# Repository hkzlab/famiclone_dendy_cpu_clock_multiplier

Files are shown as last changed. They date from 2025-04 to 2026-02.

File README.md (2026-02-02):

# Famiclone Dendy CPU clock multiplier

## DISCLAIMER

Any use of this project is **under your own responsibility**.
You will be responsible of checking the correct construction and functionality of your board.
By using this project You will agree that I cannot be held responsible if it will destroy any of your devices, damage your computer, burn down your house or whatever.

### Sponsorship

PCBWay_logo

This project is sponsored by [PCBWay](https://pcbway.com)!

PCBWay specializes in manufacturing high-quality PCBs and makes them affordable to hobbyist and professionals alike.

The range of services they offer include PCB prototyping, assembly, instant quotes for your order, a verification process by a team
of experts and an easy to use, hassle-free order process.

I am extremely grateful to them, as they sponsor most of my projects, and allow me to move them forward at a pace I wouldn't be able to sustain otherwise!

## Introduction

This board is a clock multiplier for cheap Dendy Famiclone CPUs, so they can be used in NTSC systems.

You can read about Dendy Famiclones timings [here](https://forums.nesdev.org/viewtopic.php?t=20931).

Fundamentally, NTSC and "Dendy" Famicoms have the same CPU clock / PPU clock ratio of 1:3, but Dendys are meant to work with 26.601712 Mhz frequency,
instead of the standard 21.47727 Mhz frequency for NTSC Famicoms/NES.

NTSC CPUs have an internal clock divisor of 12 (21.47727 / 12 ~= 1.790Mhz), while Dendy CPUs (except for older models) have a divisor of 15 (26.601712 / 15 ~= 1.773Mhz).
The rest of the core should be the same. Hopefully.

This board should bridge the gap making a cheap Dendy CPU work on an NTSC system by multiplying the input clock of the CPU by 1.25: 21.47727 x 1.25 = 26.8465875, which,
divided by 15 yields ~1.789Mhz, almost the same as the NTSC CPU.

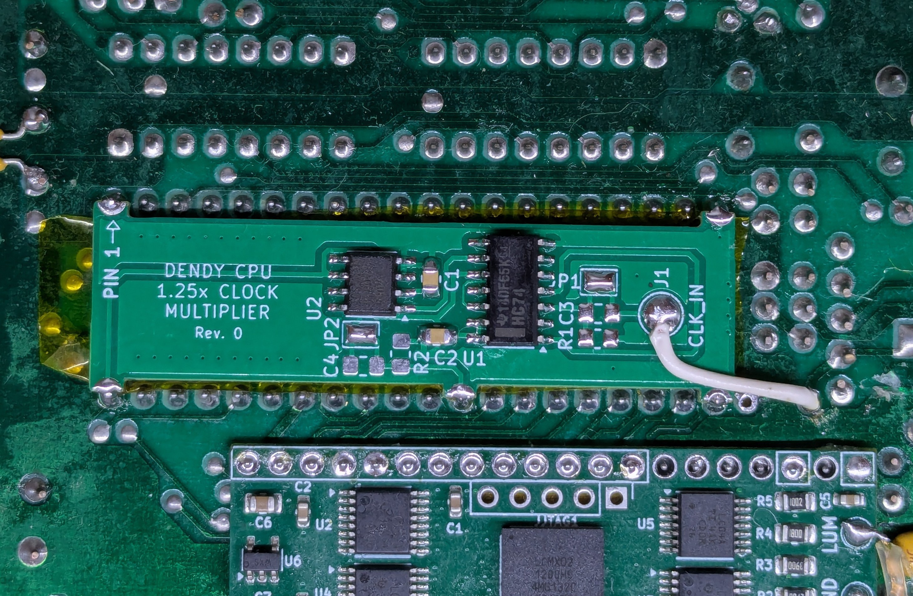
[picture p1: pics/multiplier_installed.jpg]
Rev. 0 board installed in a Famicom


The board takes the input clock, divides it by 4 using a 74'74, then multiplies the result by 5 using an ICS501 PLL, 5/4 is 1.25 :)

### Rev. 1 "Between sockets" installation

Rev. 1 boards can be installed either on the underside of the motherboard, which requires then modifying the motherboard itself to interrupt the clock that goes to pin 29 of the CPU or,
optionally, between two DIP40 sockets (one on the motherboard and the one where you'll plug the CPU in).

You'll need an open-frame socket of the type shown in the picture, you'll have to cut and isolate pin 29 on the top socket (as shown in picture) and then route a wire to pick up the clock
signal from the motherboard.

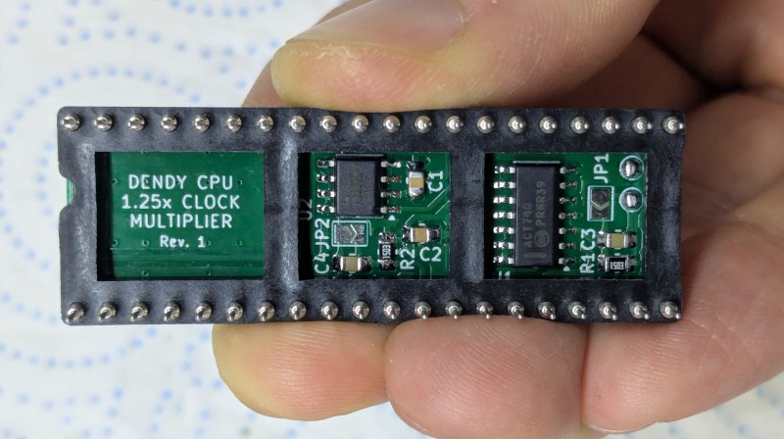
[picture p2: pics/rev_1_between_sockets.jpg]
Photo of a Rev.1 board between two sockets, showing how the components fit through the open frame


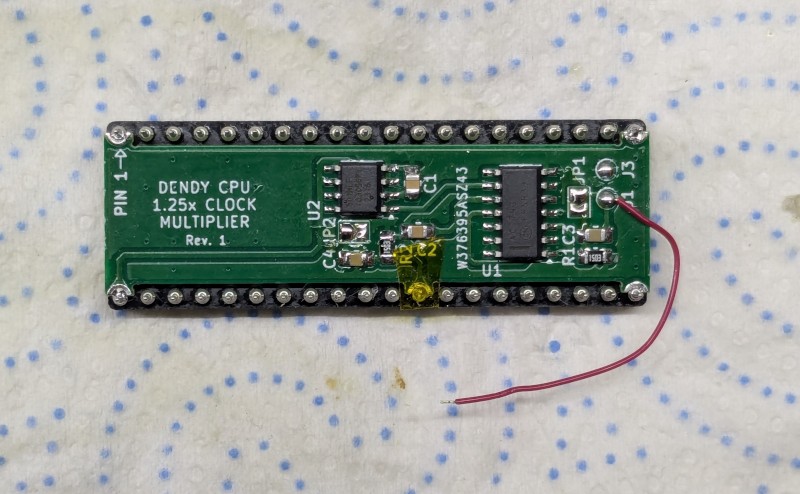
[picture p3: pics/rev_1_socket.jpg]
Photo of Rev.1 soldered beneath a socket, showing how pin 29 is isolated


If you go this route, **order boards with 1mm thickness and not 1.6!**

### Ordering the boards

You can order the board for this project at [PCBWay](https://www.pcbway.com/project/shareproject/Famiclone_Dendy_to_NTSC_CPU_adapter_Clock_Multiplier_e8107b82.html) and support me or download 
the gerbers and have them printed wherever you like!!!

## Hardware

The board was designed with [KiCad](https://kicad.org/) EDA.

### Bill of Materials

| Component | Qty | Type / Value | Notes |
| --- | --- | --- | --- |
| C1 |  1  | 10nF/16V ceramic cap, 0805 | |
| C2 |  1  | 100nF/16V ceramic cap, 0805 | |
| C3, C4 |  2  | 220pF/16V ceramic cap, 0805 | Optional, install only if you wish to decouple the clocks. Not needed in my tests. |
| R1, R2 |  2  | 150K resistor, 0805 | Optional, install only if you wish to decouple the clocks. Not needed in my tests. |
| U1 |  1  | 74HC/HCT/LS74, SOIC-14 | Bypassing the input clock decoupling I was able to use an 'HC on a Famicom  |
| U2 |  1  | ICS501 PLL, SOIC-8 | |

### Assembly

If you don't need to decouple the input and output clocks, you can leave out C3, C4, R1 and R2, and just close the JP1 and JP2 bridges. The rest of the components are needed.

The board is meant to be soldered on the underside of the motherboard, right under the CPU. I do recommend to put the CPU in a socket if it is not already.

Also, note that the ~26Mhz clock getting to the CPU must be intercepted and interrupted. It's quite easy to do on a Famicom, as it is sufficient to lift a leg of the decoupling capacitor C9.
The ~26Mhz clock must then be fed to the multiplier via pad J1. The empty pad that housed C9, on the Side of the Q3 transistor, is perfect for this.
In case you are installing this in a Famiclone/NES, you will have to change the location where you tap the signal from.

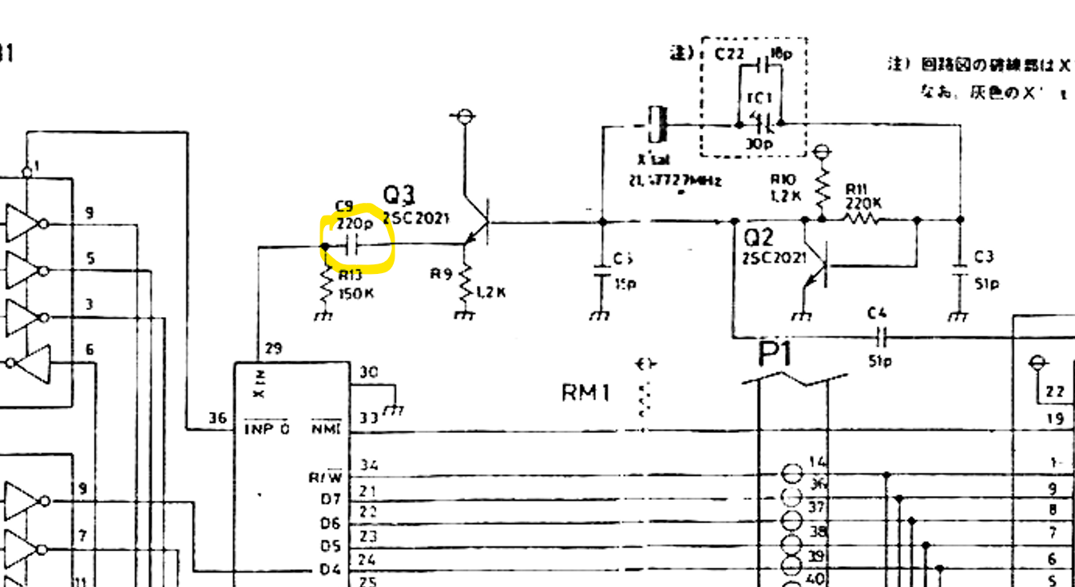
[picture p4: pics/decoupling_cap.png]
Detail of Famicom schematic


Note that the part of the PCB without components is the part that must face the motherboard. It is a good idea to put some tape between this PCB and the motherboard, to avoid potential shorts.

## Compatibility

I'll keep this table updated when I test new CPUs with this adapter.

| CPU Type  | Compatible | Notes |
| --- | --- | --- |
| TA-03NP1  | ❌ | Works, but has severe glitching and speed issues in some games  |
| UA6547P (old model, /16 divisor) | ❌ |  Works, but has severe glitching in games  |
| UA6547P (/15 divisor) | ✔️ | It Works! |
| GM6527 (/15 divisor) | ✔️ | It Works! |

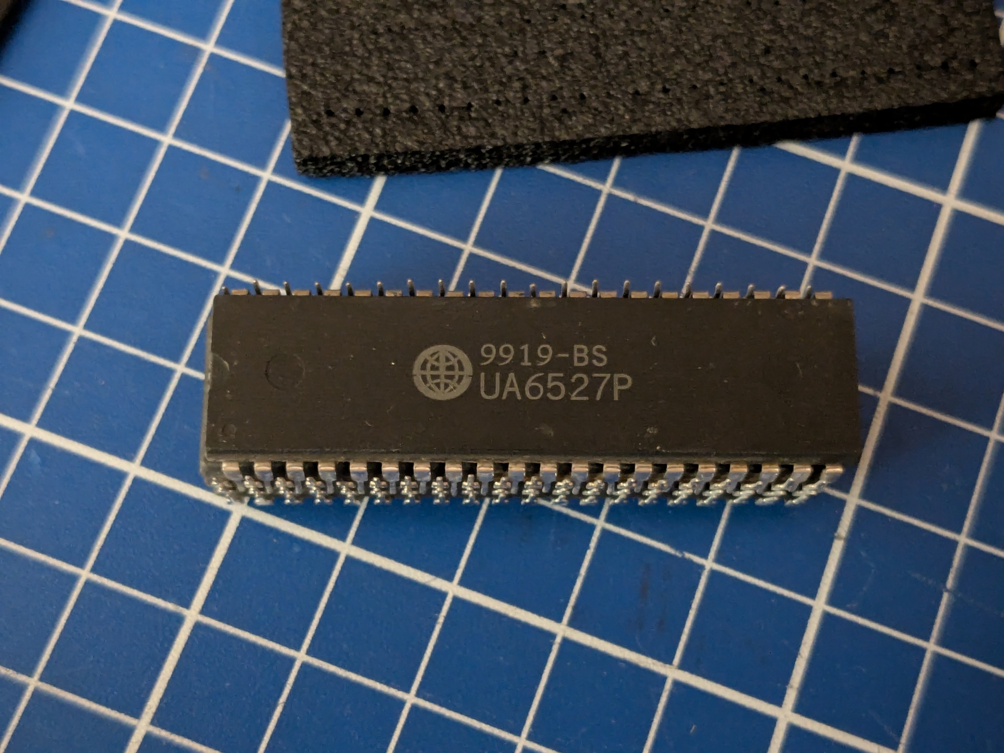
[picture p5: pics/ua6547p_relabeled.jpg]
Photo of a relabeled UA6547P


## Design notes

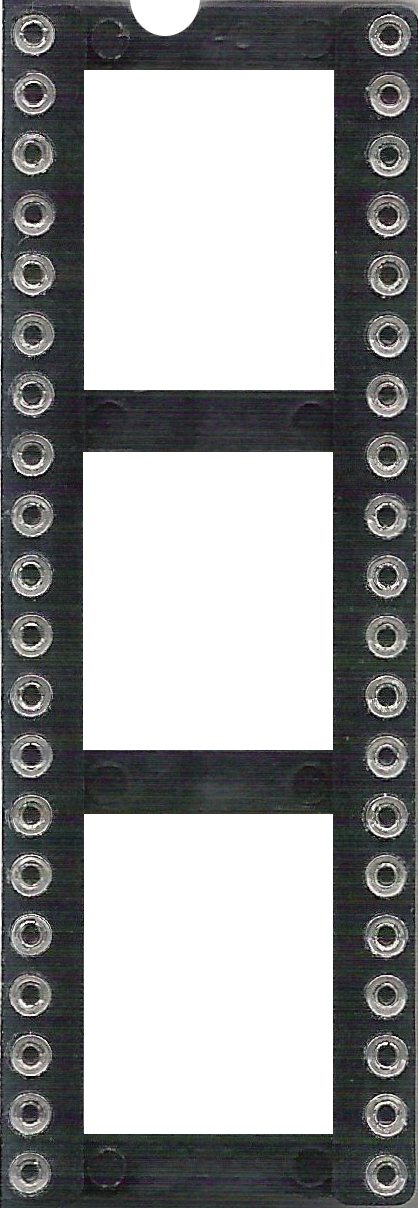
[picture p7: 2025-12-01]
graphics/dip_40_socket.png

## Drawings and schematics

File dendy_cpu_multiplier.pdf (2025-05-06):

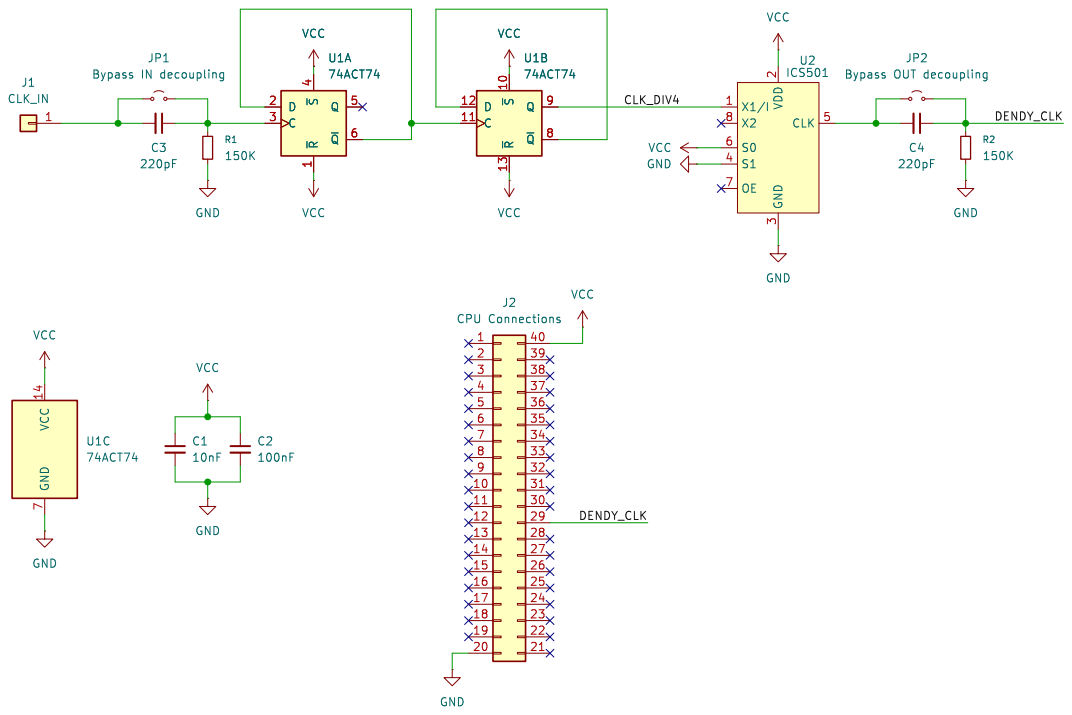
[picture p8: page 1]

JP2 Bypass OUT decoupling GND

Id: 1/1 Title: File: dendy_cpu_multiplier.kicad_sch Sheet: /

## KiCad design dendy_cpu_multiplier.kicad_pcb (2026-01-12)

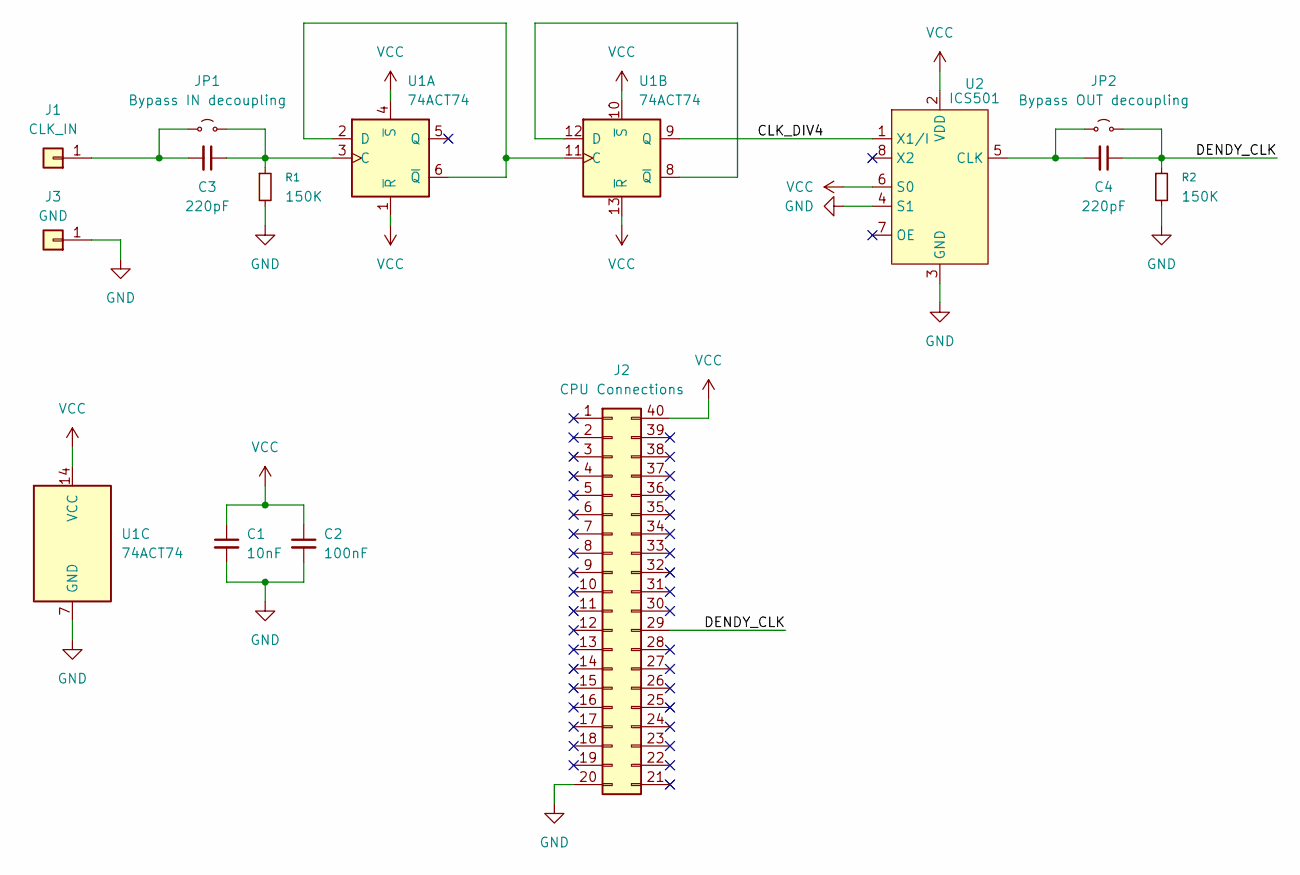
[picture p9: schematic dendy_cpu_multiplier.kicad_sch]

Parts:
C1: 10nF; C_0805_2012Metric_Pad1.18x1.45mm_HandSolder
C2: 100nF; C_0805_2012Metric_Pad1.18x1.45mm_HandSolder
C3, C4: 220pF; C_0805_2012Metric_Pad1.18x1.45mm_HandSolder
J1: CLK_IN; TestPoint_Pad_D1.5mm
J2: CPU Connections; DIP-40_W15.24mm
J3: GND; TestPoint_Pad_D1.5mm
JP1: Bypass IN decoupling; SolderJumper-2_P1.3mm_Open_TrianglePad1.0x1.5mm
JP2: Bypass OUT decoupling; SolderJumper-2_P1.3mm_Open_TrianglePad1.0x1.5mm
R1, R2: 150K; R_0805_2012Metric_Pad1.20x1.40mm_HandSolder
U1: 74ACT74; SOIC-14_3.9x8.7mm_P1.27mm
U2: ICS501; SOIC-8_3.9x4.9mm_P1.27mm

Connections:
/CLK_DIV4: U1.9 (Q), U2.1 (X1/I)
/DENDY_CLK: C4.1, J2.29, JP2.2 (B), R2.1
GND: C1.2, C2.2, J2.20, J3.1, R1.2, R2.2, U1.7 (GND), U2.3 (GND), U2.4 (S1)
unnamed: C3.2, J1.1, JP1.1 (A)
unnamed: C3.1, JP1.2 (B), R1.1, U1.3 (C)
unnamed: C4.2, JP2.1 (A), U2.5 (CLK)
unnamed: U1.2 (D), U1.6 (~Q), U1.11 (C)
unnamed: U1.8 (~Q), U1.12 (D)
VCC: C1.1, C2.1, J2.40, U1.1 (~R), U1.4 (~S), U1.10 (~S), U1.13 (~R), U1.14 (VCC), U2.2 (VDD), U2.6 (S0)

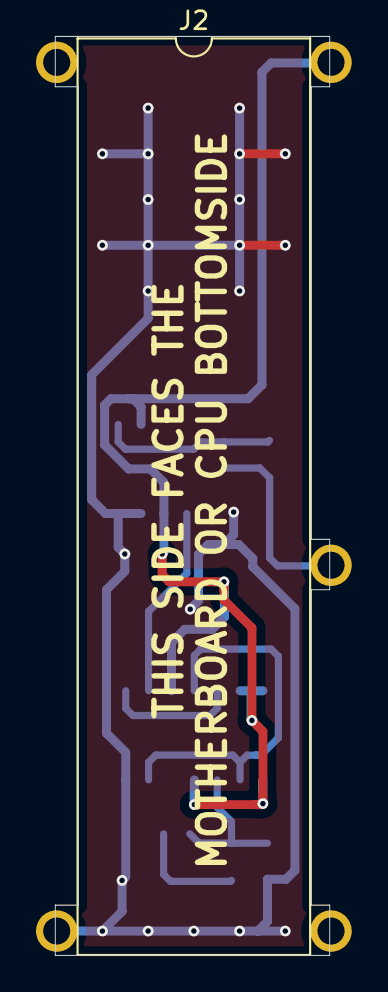
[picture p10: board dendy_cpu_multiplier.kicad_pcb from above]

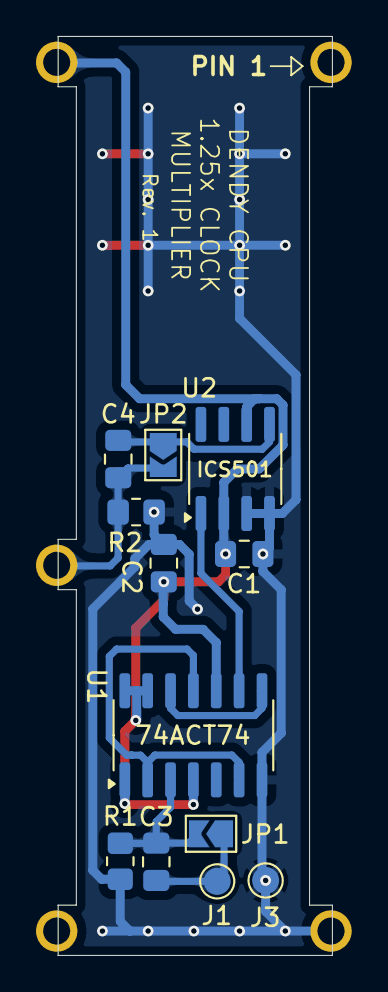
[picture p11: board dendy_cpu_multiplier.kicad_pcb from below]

Board: 2 copper layers, 15.2 x 51.1 mm, 13 parts (12 on the bottom side), 9 nets.

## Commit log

2025-04-02 Upload initial revision of the project
    [dendy_cpu_multiplier.kicad_pcb, dendy_cpu_multiplier.kicad_sch]
2025-04-03 Add some silkscreen tweaks
    [dendy_cpu_multiplier.kicad_pcb]
2025-04-05 Add datasheets, gerbers and schematics
    [dendy_cpu_multiplier.kicad_pcb]
2025-05-06 Add PDF schematic
2025-05-06 Mention PCBWay
2025-05-06 Update PCBWay link in the README
2025-12-01 Move around the components to fit into the holes of a DIP40 socket
    [dendy_cpu_multiplier.kicad_pcb, dendy_cpu_multiplier.kicad_sch]
2026-01-12 Add rev.1 PCB, untested
    [dendy_cpu_multiplier.kicad_pcb]
2026-02-02 Update the README, mention PCBWay as sponsor
